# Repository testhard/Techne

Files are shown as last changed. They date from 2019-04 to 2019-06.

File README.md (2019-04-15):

Project Techne

Il progetto consiste in una bilancia alimentare disposta di un LCD a colori che mostri i passaggi della ricetta che si vuole seguire, aiutando l'utente nel pesare gli ignredienti passo passo e compiere tutti i passaggi della ricetta. Queste ricette potranno essere caricate nella bilancia dall'utente collegandola ad un pc. Inoltre tale bilancia si occuperà anche di controllare la temperatura interna dei frigoriferi, utile per applicazioni industriali, utilizzando dei dispositivi wireless comunicanti attraverso una rete radio a 433kHz.
I moduli per il rilevmento della temperatura saranno pilotati da microcontrollers Atmega 328p, mentre la bilancia utilizzerà un STM32f405 montato su di una scheda di sviluppo apposita. 
Per rilevare il peso verrà utilizzata una cella di carico di portata max 5Kg ed un ADC a 24bit, per la temperatura verrà utilizzato un termistore ad incapsulamento in vetro ad alta precisione (1%).
I moduli wireless dovranno essere alimentati a batteria e la bilancia svolgerà anche una funzione di ricarica per i moduli.
Sarà disponibile una porta di espansione sul retro della bilancia per il futuro sviluppo di nuovi moduli aggiuntivi, ad esempio delle dock di ricarica aggiuntive o un sistema di disaggio automatico.
Il nome Techne deriva dalla mitologia greca, indica la personificazione dell'artigianato e della tecnica, è stato scelto pensando alla nostra bilancia come un fine strumento al servizio dell'arte culinaria che ancora oggi rimane il fiore all'occhiello dell'artigianato italiano. Questo oggetto è dunque da vedere come l'affinamento della tecnica al servizio degli artigiani.

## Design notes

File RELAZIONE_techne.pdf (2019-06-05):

# TECHNE

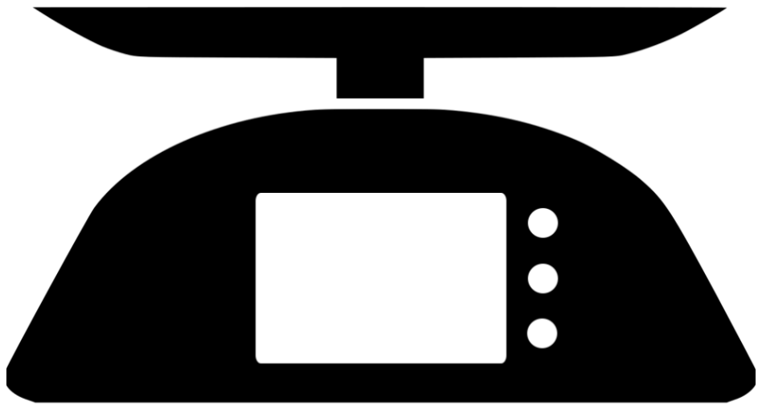
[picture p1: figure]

## Mattia Testa Michael Gentile

5^EI

Techne indica nella mitologia greca la personificazione della tecnica, dell'artigianato e della precisione. È di questa affermazione che la creazione del progetto si è fatta portatrice, sviluppando una bilancia precisa ed affidabile nonché facile da usare seppure le sue particolarità dissimilanti da tutte le bilance. È difatti dotata di un card reader SDHC che viene sfruttato per poter accedere a delle ricette durante l'uso della bilancia stessa, le quali vengono generate da un programma su computer dotato di interfaccia grafica. Non è dunque una semplice bilancia, bensì uno strumento che rende facile cucinare per chiunque, mostrando gli ingredienti delle ricette, proporzionati a piacere, passo dopo passo su un display LCD con un'interfaccia intuitiva e di facile utilizzo per chiunque, usando solo 3 pulsanti per la navigazione.

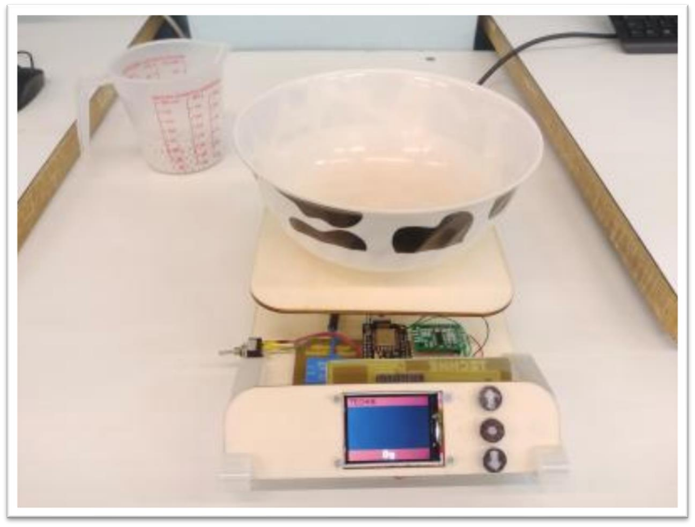
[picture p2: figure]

La struttura di Techne è realizzata completamente (colla e viti escluse) in materiali biodegradabili e provenienti da fonti naturali. Questi materiali sono 2:

Acido polilattico (PLA):
L'acido polilattico è il polimero dell'acido lattico la cui temperatura di fusione è di 180°C. Viene prodotto dalla fermentazione attraverso un batterio del genere lactobacillus di zucchero, melasse e siero di latte. Questa plastica diviene biodegradabile in seguito a idrolisi, a temperatura maggiore di 60°C e umidità superiore al 20%. Mentre la biodegradazione avviene in natura in un tempo variabile da 1 a 4 anni a seconda delle
condizioni | ambientali | in | cui | è | stato
abbandonato. | Largamente | utilizzato | nei
sistemi di prototipazione rapida, è il materiale più usato nelle tecniche di stampa 3D FDM (Fused Deposition Modeling), la stessa tecnologia utilizzata per la produzione di diversi supporti e parti meccaniche in Techne. In particolare è stato usato per la creazione dei piedi di appoggio, per una sbarra strutturale posizionata sotto la cella di carico per impedire la deformazione del piano inferiore, per il sostegno del pannello frontale, per l'incastro tra il piatto e la cella di carico e per il sostegno della stessa.

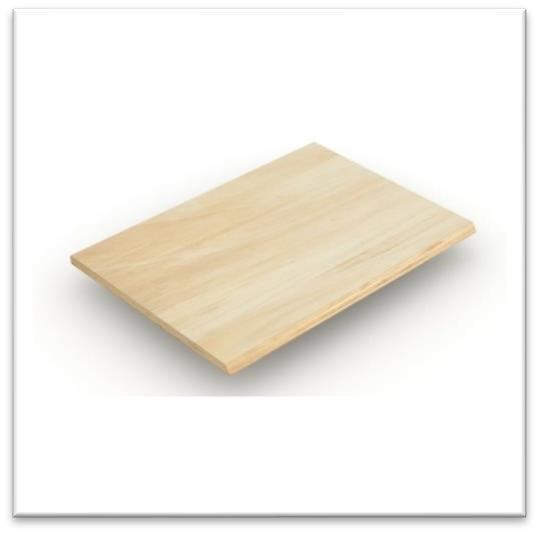
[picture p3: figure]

Legno compensato:

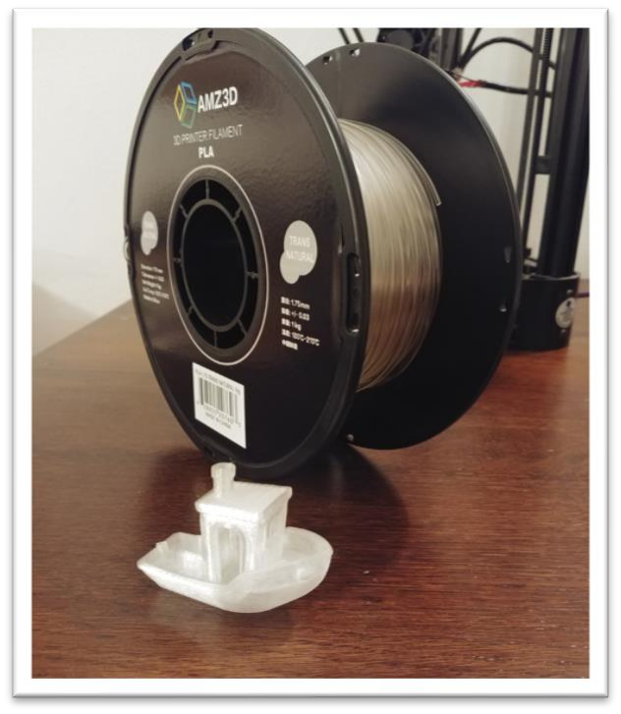
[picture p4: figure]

Con uno spessore di appena 4mm risulta essere un materiale morbido, facilmente lavorabile e molto leggero. La sua decomposizione avviene in natura tra 1 e 3 anni. È stato tagliato utilizzando una CNC a taglio laser ed è stato usato per la creazione della base, del piatto e del pannello frontale di Techne.

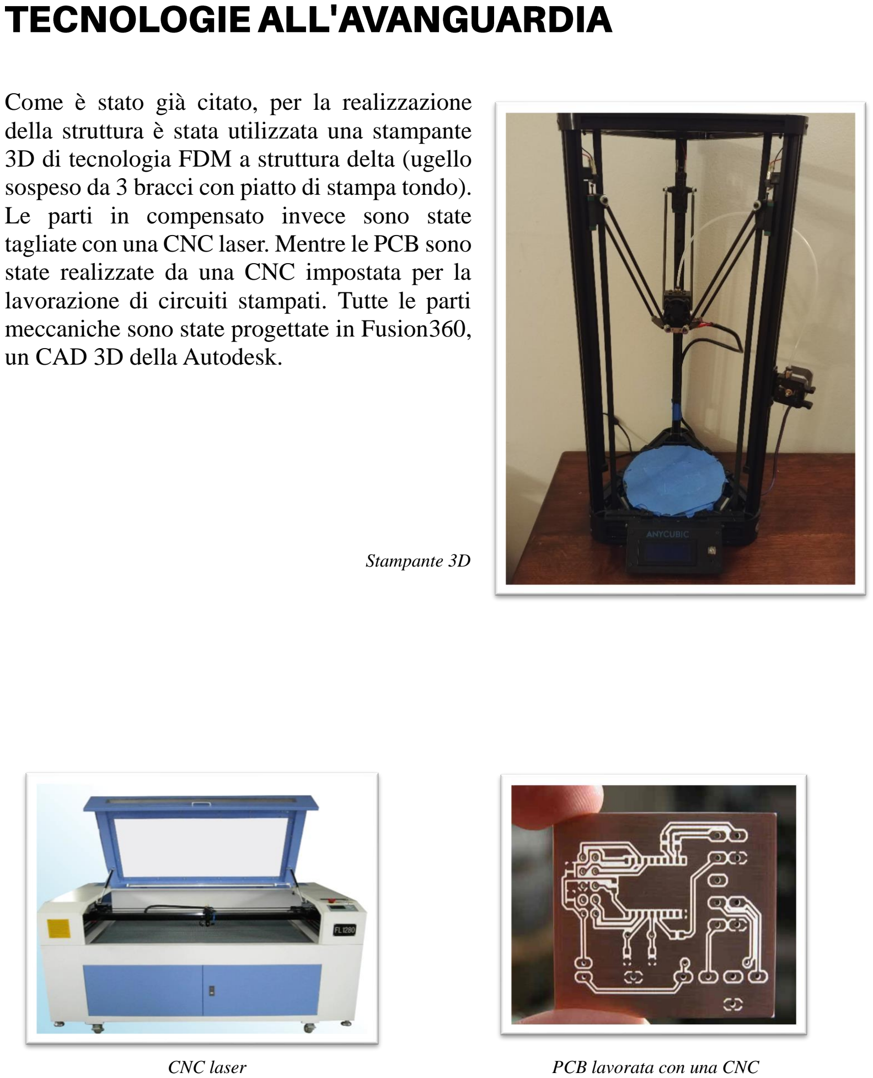
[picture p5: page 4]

Come è stato già citato, per la realizzazione della struttura è stata utilizzata una stampante 3D di tecnologia FDM a struttura delta (ugello sospeso da 3 bracci con piatto di stampa tondo). Le parti in compensato invece sono state tagliate con una CNC laser. Mentre le PCB sono state realizzate da una CNC impostata per la lavorazione di circuiti stampati. Tutte le parti meccaniche sono state progettate in Fusion360, un CAD 3D della Autodesk.

Stampante 3D

CNC laser | PCB lavorata con una CNC

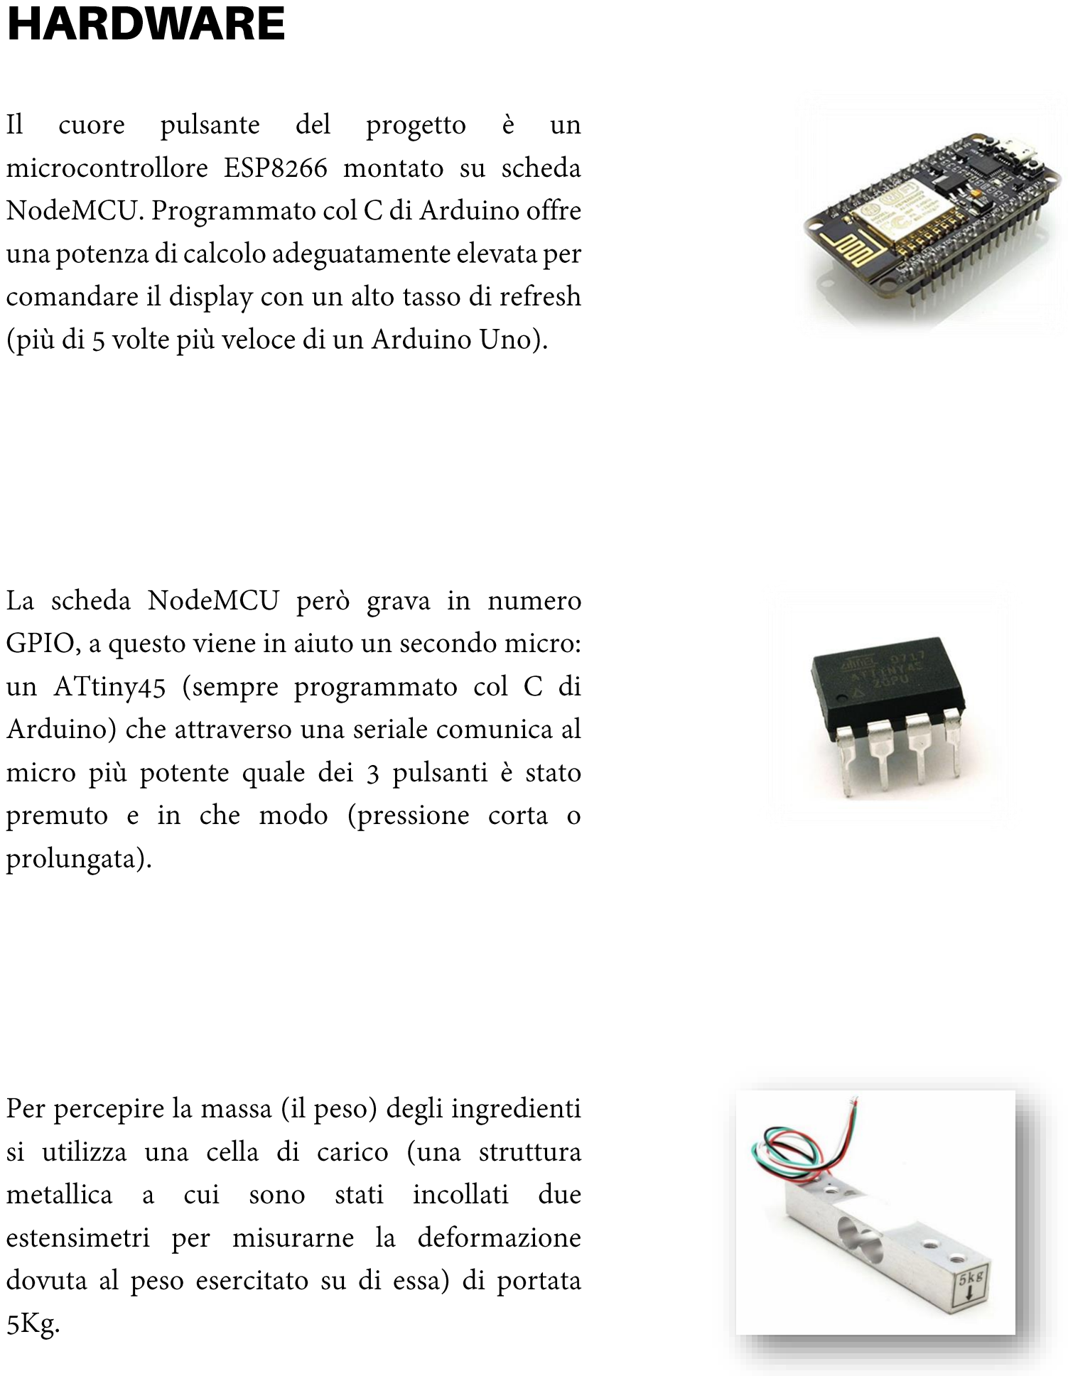
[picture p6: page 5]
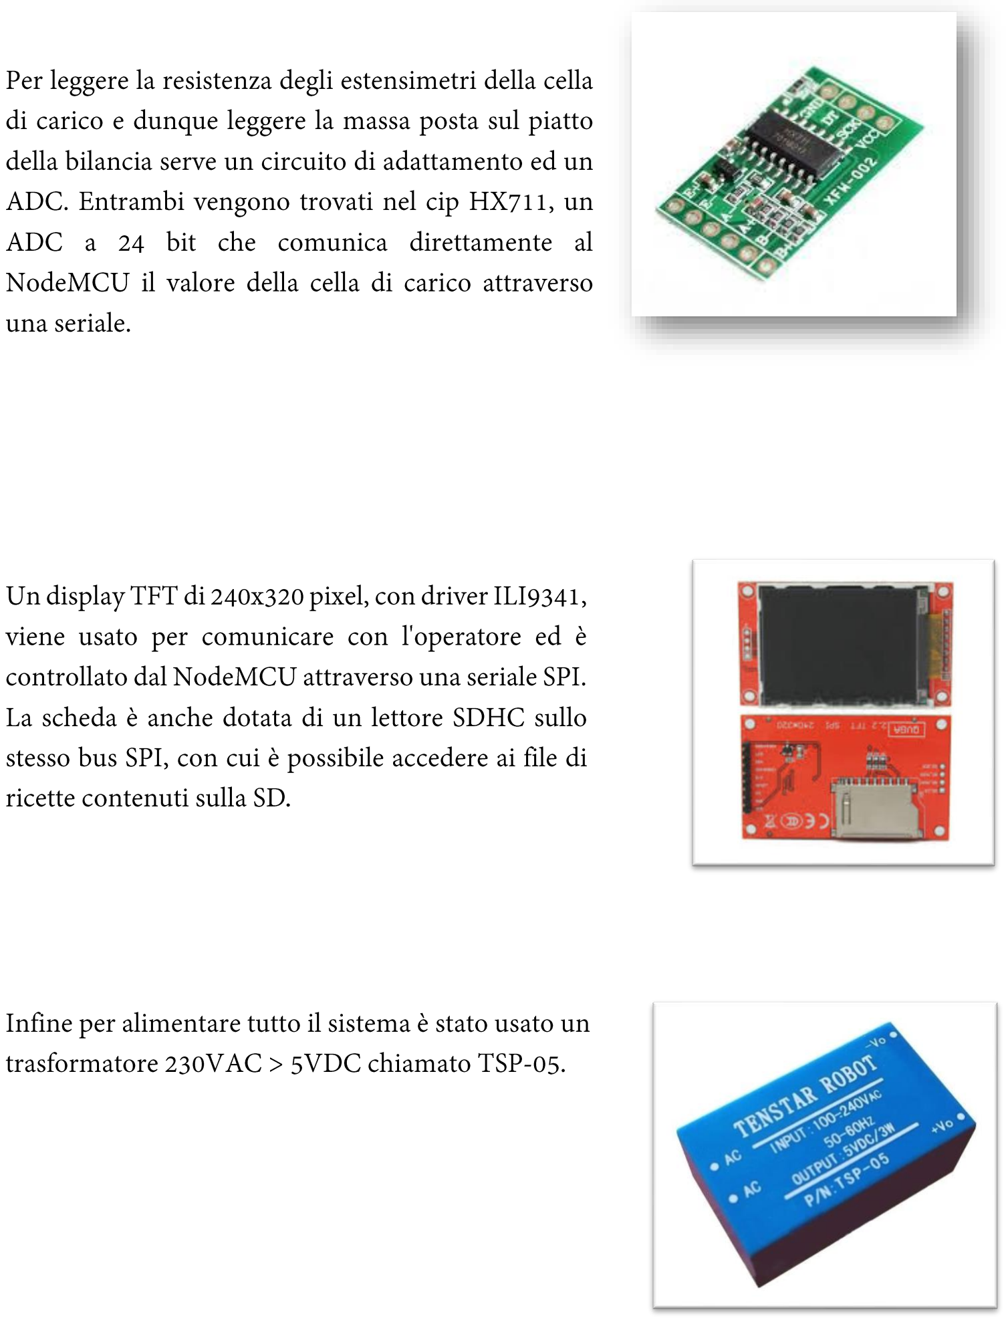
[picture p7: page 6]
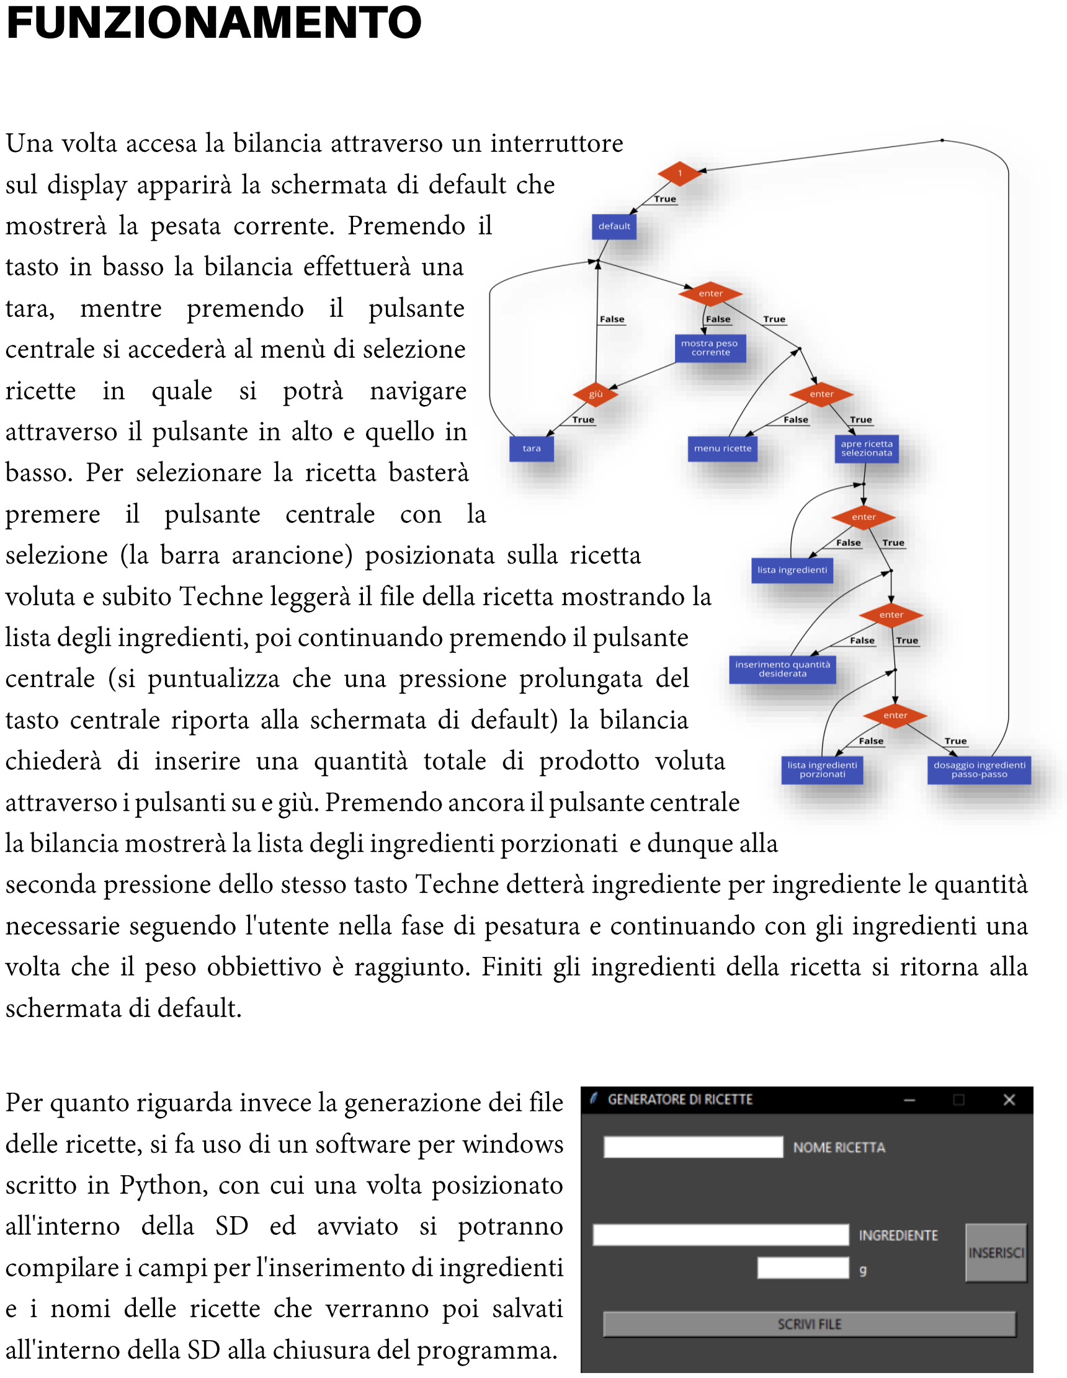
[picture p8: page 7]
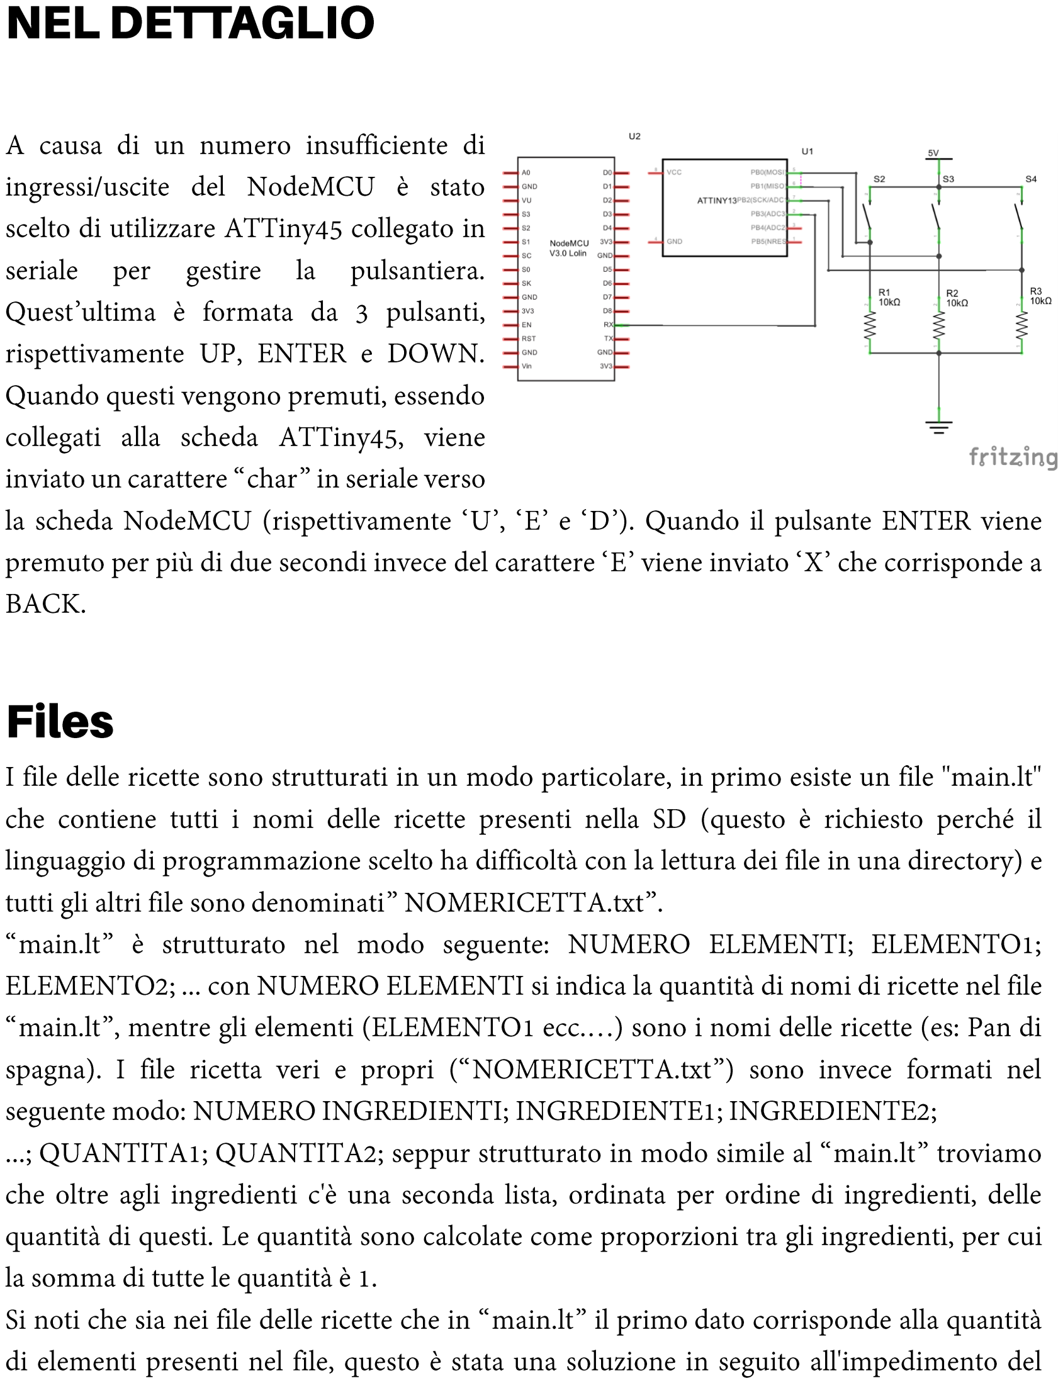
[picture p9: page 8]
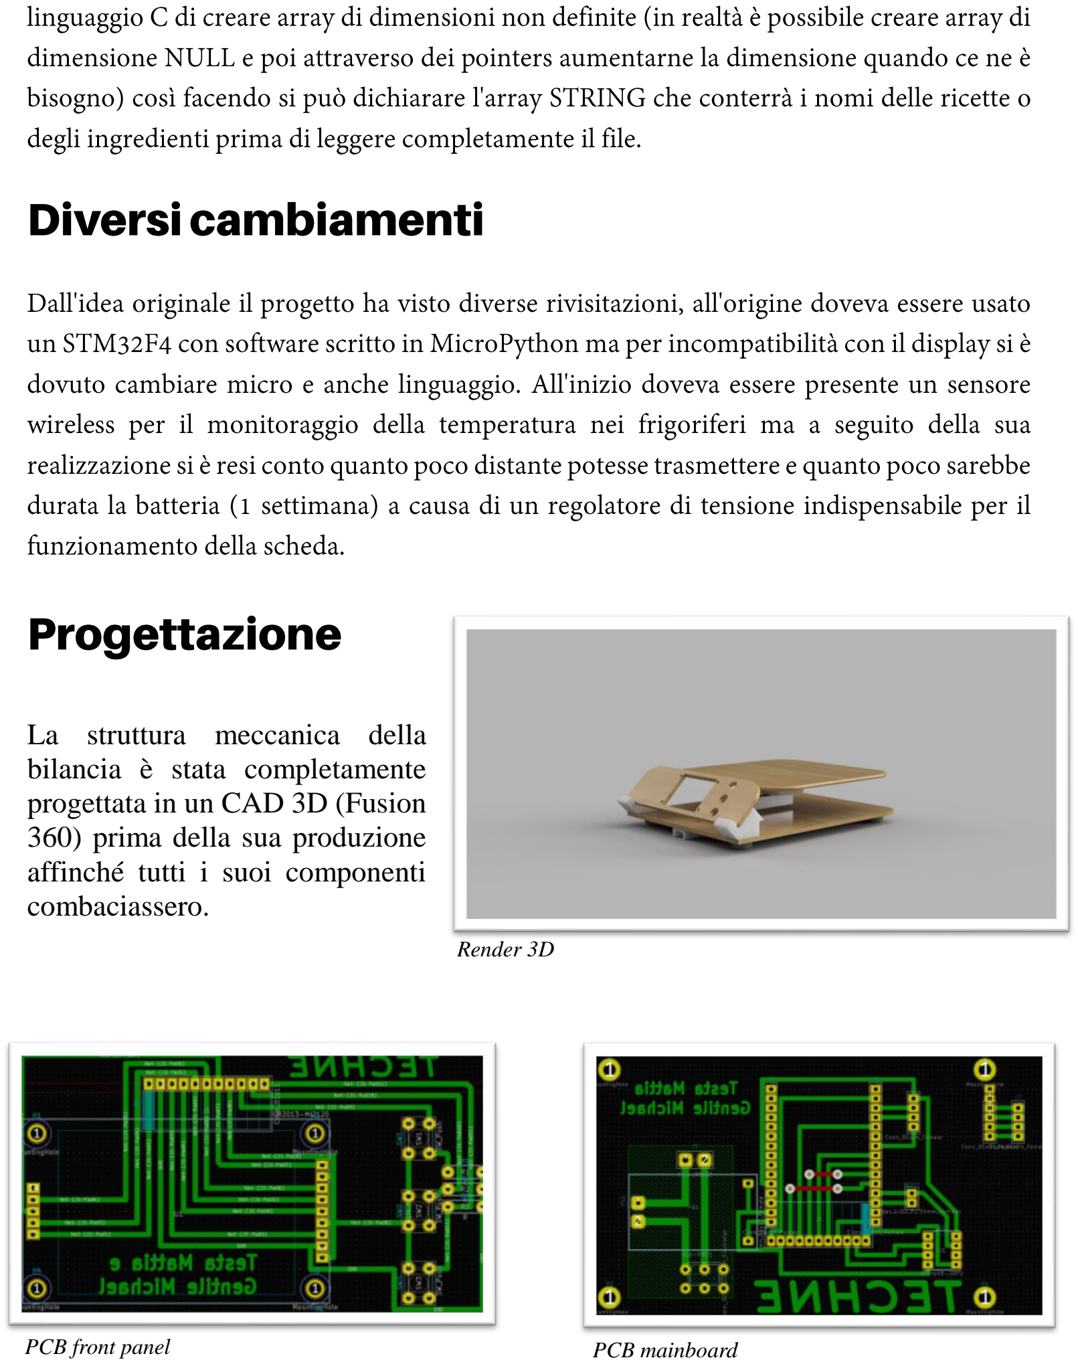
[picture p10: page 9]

La struttura meccanica della bilancia è stata completamente progettata in un CAD 3D (Fusion
360) prima della sua produzione affinché tutti i suoi componenti combaciassero.

Render 3D

PCB front panel | PCB mainboard

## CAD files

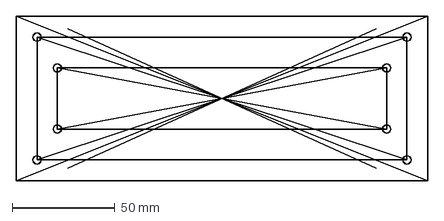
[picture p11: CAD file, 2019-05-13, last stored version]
DXFs/domingo2.dxf
200.2 x 80.0 mm

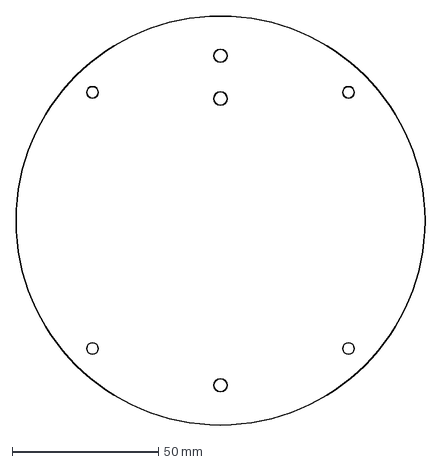
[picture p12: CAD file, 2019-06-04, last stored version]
pippo.dxf
140.0 x 140.0 mm

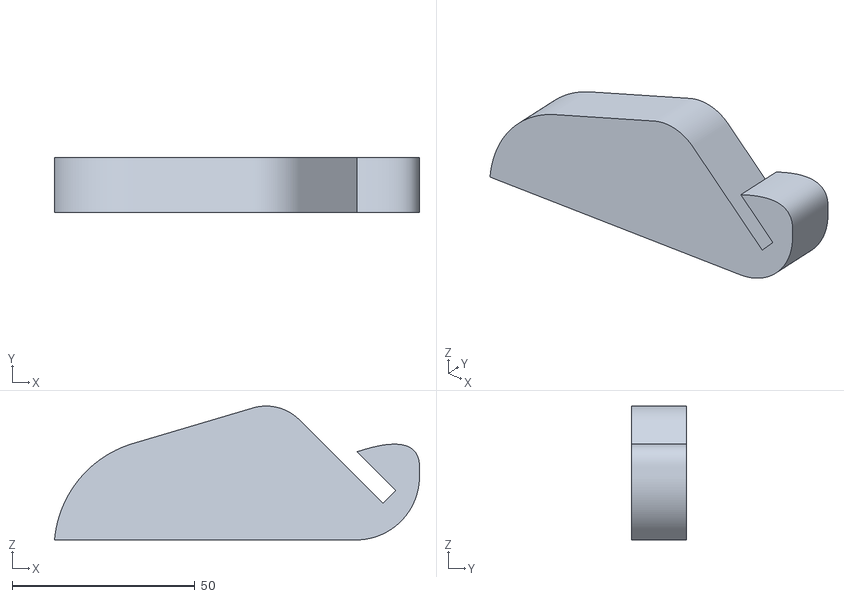
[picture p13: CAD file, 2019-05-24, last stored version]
braccino.stl
99.9 x 15.0 x 36.6

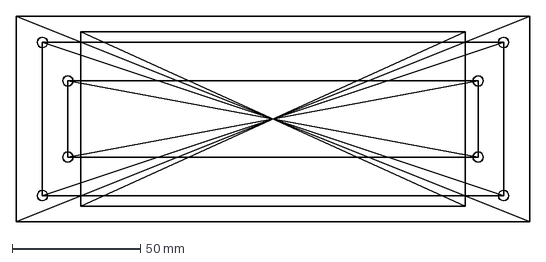
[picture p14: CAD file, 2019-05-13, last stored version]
DXFs/domingo.dxf
200.2 x 80.0 mm

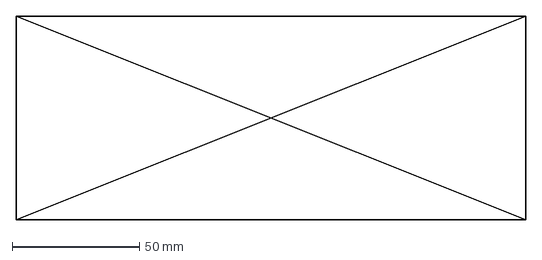
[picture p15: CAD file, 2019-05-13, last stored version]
DXFs/domingo1.dxf
200.2 x 80.0 mm

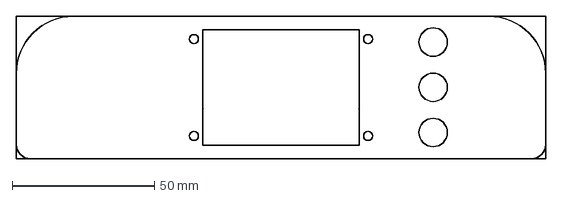
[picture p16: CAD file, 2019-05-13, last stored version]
DXFs/techne.dxf
186.0 x 50.0 mm

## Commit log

2019-04-30 Add files via upload
    programma per una gestione di menu primitiva letto da cd e mostrato su lcd
2019-05-04 Add files via upload
    arduino code to transmit buttons states via serial
